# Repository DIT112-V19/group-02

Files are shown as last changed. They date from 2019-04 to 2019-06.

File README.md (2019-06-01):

## SafeSweeper (Group-02)  

*A Cheap and Safe way of Disabling Land Mines*
### Who?
We are seven software developers (listed at the bottom) aimed at delivering a product to our client team (listed below) who are looking for an innovative car that could add value to the client and the society as a whole.

### What?
A cheap, small, remotely driven car with the capabilities of detecting mines to enable them to be safely disarmed.
This project relates to development of mobile application that interacts and control the small car's hardware which is operated by software that is described in detail below.

### Why?
Anually, over [5000](http://www.the-monitor.org/en-gb/reports/2017/landmine-monitor-2017/casualties.aspx) innocent people are injured by land mines. Most of those are civilians, which makes this a huge humanitarian issue.
Disabling land mines could be unsafe for humans and animals involved. The use of a light weight small car with capability of moving through a specific field, by avoiding obstacles, would facilitate the process realising the aforementioned purpose.

### Hardware
The following are some of the hardware that are currently used in development. As the project develops, the list could be updated depending on the need of the project which aims to provide a satisfactory product for the client.
The use of RFID and its reader could model the mines and the sensor respectively.

* Smartcar chassis
* Smartcar shield
* Arduino Mega
* Arduino Bluetooth module
* L293D H-bridge
* GY-50 gyroscope module
* Odometers
* Velleman VMA405 RFID-module

### Software
* [Android Studio](https://developer.android.com/studio) - IDE for Android applications
* [Arduino IDE](https://www.arduino.cc/en/main/software) - IDE for Arduino boards

### Arduino libraries
* [smartcar](https://github.com/platisd/smartcar_shield) - Library for Arduino based vehicles
* [RFID-RC522](https://github.com/song940/RFID-RC522) - Library for the RFID-reader

### Android libraries
* [GSON](https://github.com/google/gson) - A Java serialization/deserialization library to convert Java Objects into JSON and back
* [Google Maps SDK](https://developers.google.com/maps/documentation/android-sdk/intro) - To implement a google map in application
* [Mockito](https://site.mockito.org/) - Mocking framework for java unit tests

### Presentation
* [Video Demonstration of Product](https://youtu.be/ye_FWu3hwkU)

### Client Team
* Dimitrios Platis
* Jacob Olsson
* Ilja Pavlov

### Developers
* Adam Klevfors
* August Axelsson
* Eyuell Hailemichael
* Hannah Maltkvist
* Marcus Aronsson
* Oskar Lundberg
* Sebastian Baszczynski

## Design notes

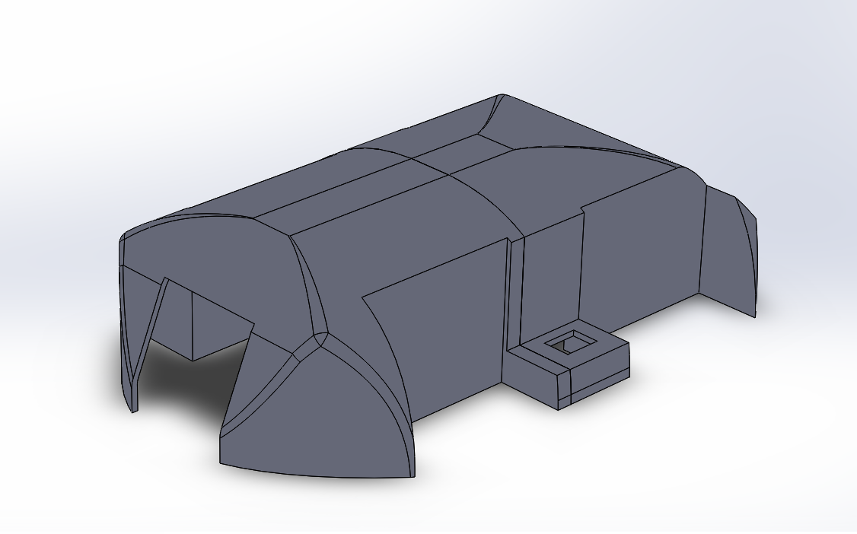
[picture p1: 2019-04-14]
chassi/CasePrototype.png

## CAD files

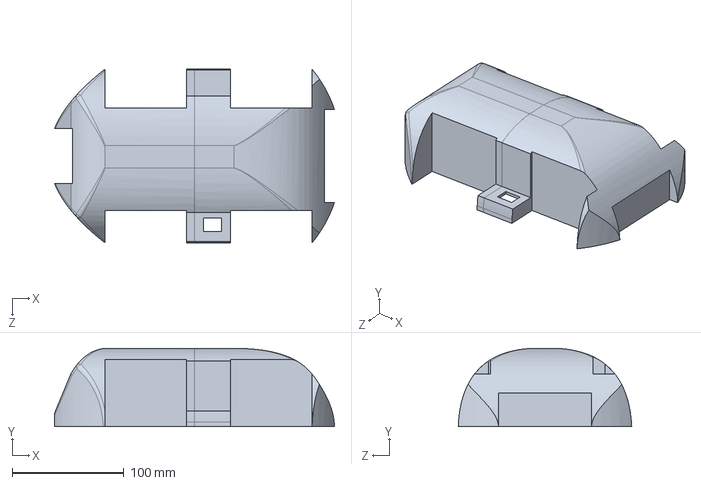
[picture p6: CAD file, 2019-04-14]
chassi/Case.SLDPRT
250.0 x 70.0 x 155.0 mm

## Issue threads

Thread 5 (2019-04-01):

Car drags to the left when it should drive in a straight line

malties, 2019-04-01:
Need to correct the route so the car actually drives in a straight line.
(As a SaveSweeper driver, I want the car move straight without deviation when I do not steer to any other direction so that  I could head in my direction of interest.)

Closed 2019-04-01.

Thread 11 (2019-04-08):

Basic Android app

MarcusAronsson1, 2019-04-08:
# User story
As a SafeSweeper operator, I want to be able to start an app for the car on my Android smartphone so that I can see the available actions and select them.

# Acceptance criteria
- [x] The app starts without crashing
- [x] The user is able to click the buttons

# To reproduce
#### Steps to reproduce the behavior:

- Install app on Android smartphone.
- Wait for app to start.
- Click on any button inside the app.

MarcusAronsson1, 2019-04-10:
Pushed to app_dev branch for now.

MarcusAronsson1, 2019-04-10:
It's done in app_dev branch.

Closed 2019-04-10.

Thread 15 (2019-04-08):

Add GPS module to the car

MarcusAronsson1, 2019-04-08:
## User Story
As a SafeSweeper operator I want to have a GPS on the car so that I can keep track of it.

## Acceptance criteria

- [x] GPS-module receives power.
- [x] GPS-module prints output to the serial monitor.

## To Reproduce

#### Steps to reproduce the behavior:
* Start the car.
* Check if GPS-module receives power.
* Check if the serial monitor displays info from the GPS-module.

Closed 2019-05-07.

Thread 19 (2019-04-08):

Continuous movement avoiding obstacles

eyuell, 2019-04-08:
## User Story
As an operator of SafeSweeper, I want the car to be able to move around while avoiding obstacles, so that the I could use the time for other purposes while the car auto maneuvers.

## Acceptance criteria

- [ ] The car moves straight unless there is obstacle at a distance of 30 cm.
- [ ] The car changes direction as long as there is obstacle and continue moving in direction of no obstacle.

## To Reproduce

#### Steps to reproduce:

After the car is on automated mode, it automatically moves forward.
When there is an obstacle, the car rotates to changes directions.

Closed 2019-04-11.

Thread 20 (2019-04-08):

Get readings from the gyroscope

MarcusAronsson1, 2019-04-08:
## User Story
As a SafeSweeper operator I want to know in which direction the car is pointing so that I know where its going to go.

## Acceptance criteria
- [x] Gyroscope is connected to car.
- [x] Serial monitor prints readings from the gyroscope.

## To Reproduce
#### Steps to reproduce the behavior:
* Start the car.
* Check if the serial monitor shows readings from the gyroscope.

platisd, 2019-04-08:
Looks great! However please use the term "Acceptance criteria" as the definition of done refers to something else (specifically "when you consider any story done").

Closed 2019-04-10.

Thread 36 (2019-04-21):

Firmly solder RFID scanner onto the car.

MiddleTv, 2019-04-21:
## User Story
As a SafeSweeper operator, I want to be reinforced that the RFID module will be soldered in place to ensure that even in the roughest conditions the reader won't fall off.

## Acceptance criteria

- [ ] RFID module won't drop whilst car is moving
- [ ] RFID module can't be removed with finger force
- [ ] RFID module won't fall off when car is dropped from small height

## To Reproduce
#### Steps to reproduce the behavior:
* Try to remove RFID by pulling it off with bare fingers
* Drop the car from an appropriate height of 10cm
* Drive the car around

platisd, 2019-04-22:
Please don't attach anything permanently to the car or try to drop it from any height :rofl:

MarcusAronsson1, 2019-04-22:
We're not allowed to solder on the car.

platisd, 2019-04-22:
Well, you're not allowed to solder **on** the car, however keep in mind that there's the PCB design workshop coming up next, which will give you the chance to create your own board where you can solder whatever you want on it! So perhaps you can think of a smart way to connect things steadily with a board of your own creation, up to 10*10cm in size.

PS. You wouldn't be able to solder anything on the car anyway as it's made from plastic. :stuck_out_tongue:

Closed 2019-04-22.

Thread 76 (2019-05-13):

CI error cloning submodule

MarcusAronsson1, 2019-05-13:
## Related issues
#62

## Description
Travis does not finish the test since the submodules it requires are not properly imported

## Acceptance criteria

- [x] TinyGPS library properly imported during Travis test

## To Reproduce

#### Steps to reproduce the behavior:
* Create pull request
* Let Travis run

MarcusAronsson1, 2019-05-13:
Error when @malties makes a pull request.
`$ git clone git@github.com:mikalhart/TinyGPS.git
Cloning into 'TinyGPS'...
Warning: Permanently added the RSA host key for IP address '192.30.253.112' to the list of known hosts.
Permission denied (publickey).
fatal: Could not read from remote repository.

Please make sure you have the correct access rights
and the repository exists.

The command "git clone git@github.com:mikalhart/TinyGPS.git" failed and exited with 128 during .`

Weird since the repository is public and it works when I create pull requests.

platisd, 2019-05-13:
I don't think this ever worked. :smiley:
Use `git clone https://github.com/mikalhart/TinyGPS.git` instead.

platisd, 2019-05-13:
But wait a minute, is @malties based off of an older branch perhaps? Your latest `master` has the correct `git clone` command. Which pull request is that?

MarcusAronsson1, 2019-05-13:
Yea it looks like this in the travis.yml
`- git clone https://github.com/mikalhart/TinyGPS.git $HOME/arduino_ide/libraries/TinyGPS`

MarcusAronsson1, 2019-05-13:
Oh damn, apparently her build config is an older one. I thought Travis was running with the config currently in master. How does it work then? Surely it doesn't use the local .travis.yml on @malties computer?

platisd, 2019-05-13:
Yeah, it looks like this **now**. But how does it look on the pull request you're trying?

platisd, 2019-05-13:
Travis runs two jobs by default. One on "your branch" no matter how old it is and one "on the master" if you understand what I mean. For example, you can see how #86 fails when building "on your (old) branch" but works when it builds against the `master`. This means that you should either rebase your branch according to the latest `master` or merge `master` into your branch.

MarcusAronsson1, 2019-05-13:
Ah! It makes sense now.
It tries the branch you're making the pull request from (with the config in that branch).
And it also tries if the master is passing if the pull request would have been merged (with the config in master).
Is this correct? Then the new branches we create from now on should work on both points, and the older branches should only work on the "master" test.

platisd, 2019-05-13:
> It tries the branch you're making the pull request from (with the config in that branch).
> And it also tries if the master is passing if the pull request would have been merged (with the config in master).

That is exactly what it does! :+1:

Closed 2019-05-14.

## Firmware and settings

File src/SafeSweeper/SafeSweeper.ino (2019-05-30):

#include <Smartcar.h>
#include <SPI.h>
#include <RFID.h> 
#include <stdlib.h>

//GPS     
String data = "";
boolean Mark_Start = false;
boolean valid = false;
const long arraySize = 500;  //if needed, the size can be increased
long savedLocations = 0;
String coordinates[500];    
String GGAUTCtime, GGAlatitude, GGAlongitude, GPStatus, SatelliteNum, HDOPfactor, Height,
PositionValid, RMCUTCtime, RMClatitude, RMClongitude, Speed, Direction, Date, Declination, Mode;
const String NOT_FOUND = "Not yet identified.";
const String NOT_WORKING = "gps module connection problem.";
const String TEST_VALUE = "c-83.582704 -142.186889/";
String gpsLocation = NOT_FOUND;
#define max_char 200       // number of characters to be saved
char message[max_char];    // stores the characters message from app
char previousChar;               // the previous input
byte index = 0;            // for array
String backLat = ""; //boundary 1
String frontLat = ""; //boundary 2
String leftLon = ""; //boundary 3
String rightLon = ""; //boundary 4
String currentLat = ""; //current position of car
String currentLon = ""; //current position of car
int minDistance = 100; //safe distance to allow the car drive without boundary unless specified
boolean startStoring = false; //to signal data can be stored

//Odometer:
const unsigned short LEFT_ODOMETER_PIN = 2;
const unsigned short RIGHT_ODOMETER_PIN = 3;
const int PULSES_PER_METER = 30; //for odometer
DirectionlessOdometer leftOdometer(PULSES_PER_METER);
DirectionlessOdometer rightOdometer(PULSES_PER_METER);

//Ultrasonic sensor:
boolean obstacle = false;
const unsigned int MAX_DISTANCE = 60;  //recognizable by sensor
const unsigned int MIN_DISTANCE = 20; //distance to obstacle
const int TRIGGER_PIN = 6; //D6
const int ECHO_PIN = 7; //D7
SR04 frontSensor(TRIGGER_PIN, ECHO_PIN, MAX_DISTANCE);

//Gyroscope:
const int GYROSCOPE_OFFSET = 37;
GY50 gyroscope(GYROSCOPE_OFFSET);

//RFID reader:
#define SS_PIN 4
#define RST_PIN 5
RFID rfid(SS_PIN, RST_PIN);
int serNum[5];
int cards[][5] = {{129,243,229,47,184}};

//Automatic mode:
const float CAR_SPEED = 30.0;
const int ZERO = 0;
const int MIN_B = 5;
const int EVEN = 2;

//Manual mode:
const int vfSpeed = 75; //very fast speed
const int fSpeed = 50; //fast speed
const int mSpeed = 35; //medium speed
const int sSpeed = 20; //slow speed
const int reduceSpeed = 10; //to reduce speed
const int bSpeed = -50; //50% of the full speed backward
const int slDegrees = -75; //degrees to turn left
const int lDegrees = -50;
const int srDegrees = 75; //degrees to turn right
const int rDegrees = 50;
const char MOVE_FSPEED1 = 'a';
const char MOVE_FSPEED2 = 'b';
const char GET_LOCATION = 'c';
const char MOVE_FSPEED3 = 'd';
const char MOVE_FSPEED4 = 'e';
const char MOVE_BACKWARD = 'f';
const char SHARP_LEFT = 'g';
const char STEER_LEFT = 'h';
const char STEER_RIGHT = 'i';
const char SHARP_RIGHT = 'j';
const char STAND_STILL = 'k';
const char AUTOMATIC_MODE = 'l';
const char MANUAL_MODE = 'n';
const char REPORT_MINE = 'm';
const char OUT_OF_BOUNDARY = 'o';

char input;

//Smartcar:
const int BAUD_RATE = 9600; //for serial
const int ANGLE_CORRECTION = 13;  //offset
const int BACK_ANGLE_CORRECTION = 26; //backwards offset
boolean automode = false;
BrushedMotor leftMotor(8, 10, 9);
BrushedMotor rightMotor(12, 13, 11);
DifferentialControl control(leftMotor, rightMotor);
SmartCar car(control, gyroscope, leftOdometer, rightOdometer);

void setup() {
  Serial.begin(BAUD_RATE);  //The general serial
  Serial3.begin(BAUD_RATE); //Serial for bluetooth
  Serial1.begin(BAUD_RATE); //Serial for GPS
  SPI.begin();              //Initializes the pins for the RFID reader
  rfid.init();              //Initializes the reader
  car.setAngle(ANGLE_CORRECTION);
  pinMode(14,INPUT);        //Input pin for bluetooth
  pinMode(15,OUTPUT);       //Output pin for bluetooth

  leftOdometer.attach(LEFT_ODOMETER_PIN, []() {
    leftOdometer.update();
  });
  rightOdometer.attach(RIGHT_ODOMETER_PIN, []() {
    rightOdometer.update();
  });

  // if analog input pin 0 is unconnected, random analog
  // noise will cause the call to randomSeed() to generate
  // different seed numbers each time the sketch runs.
  // randomSeed() will then shuffle the random function.
  randomSeed(analogRead(0));
}

void loop() {
  inputHandler();
  if(rfid.isCard()){                            //Detects mine        
    detectingMine();
  }
  if(automode == true){                         //Automatic mode
    autoMode();
  }
  else if (automode == false){                  //Manual mode
    manualMode();
  }
  //Serial.println(gpsLocation);                //for testing
}

void inputHandler(){
    index = 0;
    previousChar = input;
    //Reading location 
    while(Serial3.available() > 0){
      input = Serial3.read();      // Reads a character
      
      if(input == '#'){        //signal as a boundary info begins
        startStoring = true;
        if(automode)
          car.setSpeed(ZERO);
      }
      
      if(startStoring){
        if(automode)
          car.setSpeed(ZERO);
        message[index++] = input;
        delay(10);        //to slow a bit so that data could not be missed
      }
      
      if (input == '*')      //signal as a boundary info ends
      {
        String toBeSent = "";
        startStoring = false;
        if (index > 4) {  //minimum of 4 numbers for each latitude and longitude
          for (int i = 0; i < index; i++){    //preparing a string of characters
            toBeSent = toBeSent + message [i];
          }
          setBoundary(toBeSent);
          if(automode)  //check gps
            lookForGPS();
          toBeSent = "";
          index = 0;
        }
      }
    }
}

void detectingMine(){
  //if(isNewLocation()){  //uncomment if not testing
    car.setSpeed(reduceSpeed);
    car.setSpeed(ZERO);
    Serial3.write(REPORT_MINE);
    
    while(!Serial3.available()){}
    char command = Serial3.read();
    handleLocation();                           //sends GPS 
    while(command != REPORT_MINE){
      command = Serial3.read();
    }
    
    car.setSpeed(fSpeed);
    delay(500);
    car.setSpeed(reduceSpeed);
    car.setSpeed(ZERO);
  //}    //uncomment if not testing
}

void manualMode(){
  
  switch (input){
    case MOVE_FSPEED1:                          //Makes it go foward in slow speed
      car.setSpeed(sSpeed);
      car.setAngle(ANGLE_CORRECTION);
      break;
    case MOVE_FSPEED2:                          //Makes it go foward in medium speed
      car.setSpeed(sSpeed);
      car.setAngle(ANGLE_CORRECTION);
      break;
    case MOVE_FSPEED3:                          //Makes it go foward in fast speed 
      car.setSpeed(fSpeed);
      car.setAngle(ANGLE_CORRECTION);
      break;
    case MOVE_FSPEED4:                          //Makes it go foward in very fast speed
      car.setSpeed(vfSpeed);
      car.setAngle(ANGLE_CORRECTION);
      break;
    case MOVE_BACKWARD:                          //Makes it go backwards
      car.setSpeed(bSpeed);
      car.setAngle(BACK_ANGLE_CORRECTION);
      break;
    case SHARP_LEFT:                         //Makes it turn sharp left
      car.setSpeed(fSpeed);
      car.setAngle(slDegrees);
      break;
    case STEER_LEFT:                         //Makes it turn left
      car.setSpeed(fSpeed);
      car.setAngle(lDegrees);
      break;
    case STEER_RIGHT:                         //Makes it turn right
      car.setSpeed(fSpeed);
      car.setAngle(rDegrees);
      break;
    case SHARP_RIGHT:                        //Makes it turn sharp right
      car.setSpeed(fSpeed);
      car.setAngle(srDegrees);
      break;
    case STAND_STILL:                       //Makes it stop
      if(previousChar != STAND_STILL)
        car.setSpeed(reduceSpeed);
      car.setSpeed(ZERO);
      car.setAngle(ZERO);
      break;
    case AUTOMATIC_MODE:                       //letter l Switches to auto mode
      automode = true;
      break;
    case GET_LOCATION:                       //Send GPS
      lookForGPS();                 //reads GPS 
      sendGPS();
      break;
  }
}

//Automatic mode methods:
void autoMode(){
  if(backLat != "") //if boundary is defined
    lookForGPS();
  
    if(input == MANUAL_MODE){
      automode = false;
      car.setSpeed(reduceSpeed);
      car.setSpeed(ZERO);
    }
    if(!obstacleExists() && automode){
      car.setAngle(ANGLE_CORRECTION);
      car.setSpeed(CAR_SPEED);
    } 
    else {                        
        rotateTillFree();
    }
}

/**
   Rotate the car at specified degrees with certain speed untill there is no obstacle
*/
void rotateTillFree() {
  int degrees = random(30, 160);
  
  while(obstacleExists()){
    unsigned int initialHeading = car.getHeading();
    boolean hasReachedTargetDegrees = false;
    
    while (!hasReachedTargetDegrees) {
      
      rotateOnSpot(degrees, CAR_SPEED);
      int currentHeading = car.getHeading();
      
      if ( currentHeading > initialHeading) {
        // If we are turning left and the current heading is larger than the
        // initial one (e.g. started at 10 degrees and now we are at 350), we need to substract 360
        // so to eventually get a signed displacement from the initial heading (-20)
        currentHeading -= 360;
      } else if (degrees > ZERO && currentHeading < initialHeading) {
        // If we are turning right and the heading is smaller than the
        // initial one (e.g. started at 350 degrees and now we are at 20), so to get a signed displacement (+30)
        currentHeading += 360;
      }
      // Degrees turned so far is initial heading minus current (initial heading
      // is at least 0 and at most 360. To handle the "edge" cases we substracted or added 360 to currentHeading)
      int degreesTurnedSoFar = initialHeading - currentHeading;
      hasReachedTargetDegrees = smartcarlib::utils::getAbsolute(degreesTurnedSoFar) >= smartcarlib::utils::getAbsolute(degrees);
    }
  }
}

/**
   Measure and return the distance of obstacle within 100 cm
*/
int getObstacleDistance(){
  // Stop after it moves a length of safe distance
  if (car.getDistance() >= minDistance) {
    car.setSpeed(0);
    car.update();
  } else{
    //Serial.println(frontSensor.getDistance());
    return frontSensor.getDistance();
  }
}

/**
   Checks if there is an obstacle within 100cm
*/
boolean obstacleExists(){
  int distanceToObstacle = getObstacleDistance();
  
  if(distanceToObstacle < MIN_DISTANCE && distanceToObstacle > MIN_B){
    return true;
  } else {
    return false;
  }
}

/**
   Rotate the car on spot at the specified degrees with the certain speed
   @param degrees   The degrees to rotate on spot. Positive values for clockwise
                    negative for counter-clockwise.
   @param speed     The speed to rotate
*/
void rotateOnSpot(int targetDegrees, int speed) {
  speed = smartcarlib::utils::getAbsolute(speed);
  targetDegrees %= 360; //put it on a (-360,360) scale
  if (!targetDegrees) return; //if the target degrees is 0, don't bother doing anything
  /* Let's set opposite speed on each side of the car, so it rotates on spot */
  if (targetDegrees > 0) { //positive value means we should rotate clockwise
    car.overrideMotorSpeed(speed, -speed); // left motors spin forward, right motors spin backward
  } else { //rotate counter clockwise
    car.overrideMotorSpeed(-speed, speed); // left motors spin backward, right motors spin forward
  }
  unsigned int initialHeading = car.getHeading(); //the initial heading we'll use as offset to calculate the absolute displacement
  int degreesTurnedSoFar = 0; //this variable will hold the absolute displacement from the beginning of the rotation
  while (abs(degreesTurnedSoFar) < abs(targetDegrees)) { //while absolute displacement hasn't reached the (absolute) target, keep turning
    if(rfid.isCard()){                            //Detects mine        
      detectingMine();
      if (targetDegrees > 0) { //positive value means we should rotate clockwise
        car.overrideMotorSpeed(speed, -speed); // left motors spin forward, right motors spin backward
      } else { //rotate counter clockwise
        car.overrideMotorSpeed(-speed, speed); // left motors spin backward, right motors spin forward
      } 
    }
    car.update(); //update to integrate the latest heading sensor readings
    int currentHeading = car.getHeading(); //in the scale of 0 to 360
    if ((targetDegrees < 0) && (currentHeading > initialHeading)) { //if we are turning left and the current heading is larger than the
      //initial one (e.g. started at 10 degrees and now we are at 350), we need to substract 360, so to eventually get a signed
      currentHeading -= 360; //displacement from the initial heading (-20)
    } else if ((targetDegrees > 0) && (currentHeading < initialHeading)) { //if we are turning right and the heading is smaller than the
      //initial one (e.g. started at 350 degrees and now we are at 20), so to get a signed displacement (+30)
      currentHeading += 360;
    }
    degreesTurnedSoFar = initialHeading - currentHeading; //degrees turned so far is initial heading minus current (initial heading
    //is at least 0 and at most 360. To handle the "edge" cases we substracted or added 360 to currentHeading)
  }
}

//search for gps
void lookForGPS(){
  if (Serial1.available()> 0){
    gpsLocation = NOT_FOUND;
    
    if(Mark_Start){
      data = reader();
      if(data.equals("GPGGA")){
        GGAUTCtime = reader();
        GGAlatitude = reader();
        GGAlatitude+=reader();
        GGAlongitude = reader();
        GGAlongitude+=reader();
        GPStatus = reader();
        SatelliteNum = reader();
        HDOPfactor = reader();
        Height = reader();
        Mark_Start = false;
        valid = true;
        data = "";
      } else if(data.equals("GPGSA")){
        Mark_Start = false;
        data = "";
      } else if(data.equals("GPGSV")){
        Mark_Start = false;
        data = "";
      } else if(data.equals("GPRMC")){
        RMCUTCtime = reader();
        PositionValid = reader();
        RMClatitude = reader();
        RMClatitude+=reader();
        RMClongitude = reader();
        RMClongitude+=reader();
        Speed = reader();
        Direction = reader();
        Date = reader();
        Declination = reader();
        Declination+=reader();
        Mode = reader();
        valid = true;
        Mark_Start = false;
        data = "";
      } else if(data.equals("GPVTG")){
        Mark_Start = false;
        data = "";
      } else{
        Mark_Start = false;
        data = "";
      }
    }
    
    if(valid){
      if(PositionValid == "A"){
        Serial.print("Latitude:");
        //Serial.print(RMClatitude);
        String convertedLat = convertData(RMClatitude);
        //Serial.print("   ");
        Serial.println(convertedLat);
        Serial.print("Longitude:");
        //Serial.print(RMClongitude);
        String convertedLon = convertData(RMClongitude);
        //Serial.print("   ");
        Serial.println(convertedLon);
        Serial.println(" ");
        gpsLocation = "c" + convertedLat + " " + convertedLon + "/";
        currentLat = convertedLat;
        currentLon = convertedLon;
        int minDis = setMinDistance(); //to record the safe distance
        if (minDis < 0){
          outOfBoundary();
        }
        valid = false;
      } 
    }
    
    if(Serial1.find("$")){
      //Serial.println("capture");
      Mark_Start = true;
    }
  } else {
    gpsLocation = NOT_WORKING;
  }
}

//reader of GPS if triggered to read
String reader(){
  String value = "";
  int temp;
  while (Serial1.available() > 0){
    delay(2);
    temp = Serial1.read();
    if((temp == ',')||(temp == '*')){
      if(value.length()){
        return value;
      } else {
        return "";
      }     
    } else if(temp == '$'){
      //Serial.println("failure");
      Mark_Start = false;
    } else {
      //Serial.println("add");
      value+=char(temp);
    }
  }
}

//data from GPS will be converted to suitable string
String convertData(String rawString){
  char lastChar = rawString.charAt(rawString.length()-1);
  int dotAt = rawString.indexOf(".");
  String leftPart = rawString.substring(0,dotAt);
  String rightPart = rawString.substring(dotAt+1, (rawString.length()-1));
  int leftDigit = leftPart.length();
  String left1 = leftPart.substring(0, leftDigit - 2);
  String left2 = leftPart.substring(leftDigit-2);
  String newString = left1 + "." + left2 + rightPart;
  
  if(lastChar == 'W' || lastChar == 'S'){
      newString = "-" + newString;
  }
  
  return newString;
}

//Sends the Current GPS Location 
void sendGPS(){
  String gpsToBeSent = gpsLocation;
  int lengthOfChar = gpsToBeSent.length();
  if(gpsToBeSent.equals(NOT_FOUND)){
    gpsToBeSent = TEST_VALUE;  //comment if not testing
    //gpsToBeSent = "x";    //uncomment if not testing
  } else if (gpsToBeSent.equals(NOT_WORKING)){
    gpsToBeSent = "y";
  }
  
  lengthOfChar = gpsToBeSent.length();
  for(int i = 0; i < lengthOfChar; i++){
    char shoot = gpsToBeSent.charAt(i);
    Serial3.write(shoot);
  }
}

//looking for location when mine is detected
void handleLocation(){
  Serial3.end();
  lookForGPS();                             
  Serial3.begin(BAUD_RATE);
  sendGPS();
}

//check if the mine location is new
boolean isNewLocation(){
  if(gpsLocation != NOT_FOUND && gpsLocation != NOT_WORKING /*&& gpsLocation != TEST_VALUE && !isInArray()*/){  //uncomment if out in field
    if(savedLocations < arraySize && gpsLocation != TEST_VALUE)  //test value active only for test purpose
      coordinates[savedLocations++] = gpsLocation;
    return true;
  } else
    return false;
}

//convert the string of boundaries to separate latitudes and longitudes
void setBoundary(String text){
  //preparing for extraction
  text = text.substring(text.indexOf('#') + 1);
  text = text.substring(0, text.indexOf('*'));
  text = text + " ";
  
  Serial.println("new coordinate: " + text);
  
  //first part
  backLat = text.substring(0,text.indexOf(" "));
  text = text.substring(text.indexOf(" ") + 1);
  //Serial.println("new txt: " + text);

  //second part
  frontLat = text.substring(0,text.indexOf(" "));
  text = text.substring(text.indexOf(" ") + 1);
  //Serial.println("new txt: " + text);

  //third part
  leftLon = text.substring(0,text.indexOf(" "));
  text = text.substring(text.indexOf(" ") + 1);
  //Serial.println("new txt: " + text);

  //last part
  rightLon = text.substring(0,text.indexOf(" "));
  Serial.println("The locations are: ");  //for debuging
  Serial.println(backLat);
  Serial.println(frontLat);
  Serial.println(leftLon);
  Serial.println(leftLon);
}

//to check if a coordinate is already existing
boolean isInArray(){
  for (int i = 0; i < savedLocations; i++){
    if(coordinates[i].equals(gpsLocation))
      return true; 
  }
  return false;
}

//min distance to the digital boundaries
int setMinDistance (){
  int lat1Distance = getLat1Distance();
  int lat2Distance = getLat2Distance();
  int lon1Distance = getLon1Distance();
  int lon2Distance = getLon2Distance();
  
  minDistance = min(min(min(lat1Distance, lat2Distance), lon1Distance), lon2Distance);
  return minDistance;
}

//distance between car and latitude1
int getLat1Distance(){
  double latFactorLindholmen = 100000 * 1.125; //distance multiplier around lindholmen
  if(backLat != "" && currentLat != ""){
    double num1 = strtod(currentLat.c_str(), NULL);
    double num2 = strtod(backLat.c_str(), NULL);
    return (int)((num1 - num2) * latFactorLindholmen); //to convert to meters
  }
  else
    return 100;
}

//distance between car and latitude2
int getLat2Distance(){
  double latFactorLindholmen = 100000 * 1.125; //distance multiplier around lindholmen
  if(frontLat != "" && currentLat != ""){
    double num1 = strtod(currentLat.c_str(), NULL);
    double num2 = strtod(frontLat.c_str(), NULL);
    return (int) ((num2 - num1) * latFactorLindholmen); //to convert to meters
  }
  else
    return 100;
}

//distance between car and longitude1
int getLon1Distance(){
  double lonFactorLindholmen = 100000*0.6316; //distance multiplier around lindholmen
  if(leftLon != "" && currentLon != ""){
    double num1 = strtod(currentLon.c_str(), NULL);
    double num2 = strtod(leftLon.c_str(), NULL);
    return (int)((num1 - num2) * lonFactorLindholmen); //to convert to meters
  }
  else
    return 100;
}

//distance between car and longitude2
int getLon2Distance(){
  double lonFactorLindholmen = 100000*0.6316; //distance multiplier around lindholmen
  if(rightLon != "" && currentLon != ""){
    double num1 = strtod(currentLon.c_str(), NULL);
    double num2 = strtod(rightLon.c_str(), NULL);
    return (int) abs((num2 - num1) * lonFactorLindholmen);  //meters
  }
  else
    return 100;
}

//if sweeper is out of boundary
void outOfBoundary(){
    car.setSpeed(reduceSpeed);
    car.setSpeed(ZERO);
    Serial3.write(OUT_OF_BOUNDARY); //send info to app
    
    while(!Serial3.available()){}
    char command = Serial3.read();
    
    while(command != MANUAL_MODE){  //wait until manual mode is enabled
      command = Serial3.read();
    }
}

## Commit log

2019-04-01 Implemented basic movement and obstacle detection
    Fixes #2
    Fixes #3
    Fixes #4
    Fixes #5
    [SafeSweeper.ino]
2019-04-10 August and Oskar added the gyroscope function to the smart car, and we also made some test with it
2019-04-10 First app commit. Frontend with sliders and a button. Functionality to be added later.
2019-04-15 reorganised repo-structure to make it more readable
    [Case.SLDPRT]
2019-04-15 Android app bluetooth
    App can now list available bluetooth devices.
2019-04-15 Android app bluetooth connectivity
    The android app now connects to chosen bluetooth device.
2019-04-17 minor update
    added toggle switch between manual and automatic
2019-04-22 Update to manual controls "added manual steering functions and automatic steering function to application"
2019-04-24 Changed so it starts in manual mode, and added 6 as the command for switching automatic to manual
2019-04-30 thread to listen to inputs from the car
2019-05-01 fixed some issues with the threading
2019-05-01 Update to layout "Update the application's layout with 'get location' button as well as a few minor changes to the app's design"
2019-05-03 added button to acknowledge mine
2019-05-03 fixed the read if-statement so it now waits for a command from the app when it has detected a mine
    [SafeSweeper.ino]
2019-05-06 GPS and random angle inclusion related with issues #16 and #43
    [SafeSweeper.ino]
2019-05-06 Enhancement for the command-writing code, will make issues with advanced speed and steering alot easier
2019-05-06 GPS location successfully read and displayed. Related to issue #15 #16 and #40
    [SafeSweeper.ino]
2019-05-08 Added additional steering options to be initialized in the arduino code
2019-05-13 Fixed a few typos
    [SafeSweeper.ino]
2019-05-20 Location view adjustment and Array in Arduino #37 and #74
2019-05-29 add missing ino file from previous commit and update content for sweeper out of bourder #116 and #91
    [SafeSweeper.ino]
2019-05-30 Digital boundary shown on map enhancement on #116 with correction for travis
    [SafeSweeper.ino]
